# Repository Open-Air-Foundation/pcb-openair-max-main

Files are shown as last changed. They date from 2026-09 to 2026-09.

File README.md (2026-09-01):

# AirGradient Open Air Max — Hardware

> KiCad hardware design files for the [AirGradient Open Air Max](https://www.airgradient.com/professional/products/open-air-max/), a professional outdoor air quality monitor.

## Overview

Open Air Max is AirGradient's professional outdoor air quality monitor, designed for autonomous, off-grid operation. It measures PM2.5 (2× Plantower PMS5003), CO₂ (SenseAir Sunlight NDIR, 0–5,000 ppm), TVOCs/NOₓ (Sensirion SGP41), NO₂ (AlphaSense A43F) and O₃ (AlphaSense A431), plus temperature and humidity (Sensirion SHT40), in a UV-resistant, weatherproof ASA enclosure with wall or pole mounting (model O-M-1PPSTON-CE; CE, RoHS, REACH, and FCC certified).

Data is reported over Wi-Fi (2.4 GHz IEEE 802.11 b/g/n) or 4G cellular (LTE Cat 1). Power comes from a 10 W solar panel charging a user-replaceable pack of three 3,500 mAh Li-ion 18650 cells in series (3S), managed by a dedicated battery management system and a low-power design throughout.

This repository contains the monitor's main PCB: the ESP32-C6 MCU, solar/USB-C charging and power path, battery management, and the interfaces the sensor modules and the cellular CE card plug into — complete with schematics, PCB layout, bundled 3D models, and the production output set.

## Design structure

The design is a single 4-layer board (signal / power plane / ground plane / signal) drawn across three schematic sheets:

| Sheet | File | Contents |
|---|---|---|
| Root | `PCB/openair-max/One-Air-Max.kicad_sch` | MCU, power distribution, sensor and CE-card interfaces |
| Battery holder | `PCB/openair-max/Battery-Holder.kicad_sch` | 18650 battery interface and BMS |
| Solar module | `PCB/openair-max/Solar-Module.kicad_sch` | Charger and solar input conditioning |

## Repository structure

```
PCB/
└── openair-max/             # Main PCB (schematic, layout, DRC rules, production/)
libraries/                   # Shared 3D model libraries
├── 3d/                      # STEP models
└── easyeda2kicad/           # easyeda2kicad WRL models
```

## Key components

| Function | Part | Ref |
|---|---|---|
| MCU / Wi-Fi / BLE | ESP32-C6-WROOM-1-N8 | U1 |
| Buck converter | TPS62902 | U2 |
| Hardware watchdog timer | TPL5010 | U3 |
| Battery management system (BMS) | BQ7790512 (BQ76905 family) | U4 |
| Battery charger (solar + USB-C) | BQ25798 | U5 |
| Boost converter | TPS62903 | U6 |
| Power mux / load switch (RC soft-start) | TPS2117 | U7 |
| I²C-to-dual-UART bridge | WK2132 | U8 |
| EEPROM (2 Mbit, optional — DNP) | AT24CM02 | U12 |
| High-side load switches (switched sensor rails) | TPS27081A | U13–U19 |

**Power architecture:** The BQ25798 charger takes two power inputs — the solar cell on **VAC1** and USB-C on **VAC2** — and charges the 3S 18650 pack behind the BQ76905 BMS. The system rail is switched through the TPS2117 with an RC soft-start network to limit inrush current, and a 470 µF bulk capacitor ahead of the load switch provides brownout immunity.

## Plug-in modules

The gas sensors and the cellular option are separate boards that plug into this board's connectors. The assembled Open Air Max (O-M-1PPSTON-CE) carries all of them:

| Module | Repository | Connector on this board |
|---|---|---|
| SUNX CO₂ sensor module (SenseAir Sunlight, UART) | [pcb-module-sunx](https://github.com/Open-Air-Foundation/pcb-module-sunx) | `CO2` — 8-pin Molex PicoBlade: switched 5 V (VOUT2, EN_CO2 = IO5), GND, UART0 (IO0/IO1) |
| SGP41 TVOC/NOₓ sensor module (I²C) | [pcb-module-sgp41](https://github.com/Open-Air-Foundation/pcb-module-sgp41) | `I2C1` / `I2C2` — 1×4 sockets, 2.54 mm: 3.3 V, GND, SCL (IO6), SDA (IO7) |
| SHT4x temperature/humidity sensor module (I²C) | [pcb-module-sht40](https://github.com/Open-Air-Foundation/pcb-module-sht40) | `I2C1` / `I2C2` — the two sockets are identical; one takes the SGP41 module, the other the SHT4x module |
| AlphaSense ADC module — NO₂ (A43F) and O₃ (A431), I²C | [pcb-module-alphasense-adc](https://github.com/Open-Air-Foundation/pcb-module-alphasense-adc) | `NO2` — 8-pin Molex PicoBlade: switched 5 V and 3.3 V (VOUT6/VOUT5, EN_NO2 = IO4), GND, I²C |
| CE card — 4G cellular (LTE Cat 1) | [pcb-module-ce-card](https://github.com/Open-Air-Foundation/pcb-module-ce-card) | `CE1` — 8-pin Molex PicoBlade: switched 5 V and 3.3 V (VOUT4/VOUT3, EN_CE = IO15), power/reset control (IO23, IO21), UART (IO16/IO17) |

The particulate sensors (2× Plantower PMS5003) plug straight into the `PM1`/`PM2` PicoBlade sockets (switched 5 V + UART through the WK2132 bridge) and have no module board of their own. `I2C3` (4-pin, 1.25 mm; I²C) and `IO1` (8-pin PicoBlade: 5 V, 3.3 V, I²C, IO18–IO20) are spare expansion connectors.

## Toolchain

- **KiCad 10** (file format 2026-02). Symbols and footprints are embedded in the design files; all 3D models are bundled in `libraries/` and referenced project-relative — the project opens without any extra library setup.
- **[Fabrication Toolkit](https://github.com/bennymeg/Fabrication-Toolkit)** plugin — generates the Gerber/BOM/CPL production set in JLCPCB-compatible format.
- Active DRC rules are in `PCB/openair-max/One-Air-Max.kicad_dru`; `PCB/openair-max/DRC/JLCPCB.kicad_dru` is a slightly stricter JLCPCB reference template.

## Fabrication

`PCB/openair-max/production/` holds the ready-to-order set for the released version: Gerber zip, BOM, designators, and pick-and-place positions (generated with Fabrication Toolkit, LCSC part numbers for assembly at JLCPCB).

## Versioning & releases

Hardware revisions are tagged on this repository. Per-version release notes — chip-level changes and the matching production file set — are published on the [GitHub Releases](../../releases) page.

## Related repositories

- [firmware-openair-max](https://github.com/Open-Air-Foundation/firmware-openair-max) — ESP32-C6 firmware for this board
- [pcb-module-sunx](https://github.com/Open-Air-Foundation/pcb-module-sunx) — SUNX CO₂ sensor module (SenseAir Sunlight)
- [pcb-module-sgp41](https://github.com/Open-Air-Foundation/pcb-module-sgp41) — SGP41 TVOC/NOₓ sensor module
- [pcb-module-sht40](https://github.com/Open-Air-Foundation/pcb-module-sht40) — SHT4x temperature/humidity sensor module
- [pcb-module-alphasense-adc](https://github.com/Open-Air-Foundation/pcb-module-alphasense-adc) — AlphaSense ADC module (NO₂ / O₃ electrochemical sensors)
- [pcb-module-ce-card](https://github.com/Open-Air-Foundation/pcb-module-ce-card) — 4G cellular extension (CE) card; the assembled Open Air Max includes this card, fitted to the CE1 connector

## License

This is open-source hardware. The design files in this repository are licensed under the
[Creative Commons Attribution-ShareAlike 4.0 International (CC BY-SA 4.0)](https://creativecommons.org/licenses/by-sa/4.0/) license — see [LICENSE](LICENSE).

You are free to use, modify, and manufacture these designs, including commercially, provided you credit AirGradient and share derivative designs under the same license.

## Maintainers

AirGradient hardware team.

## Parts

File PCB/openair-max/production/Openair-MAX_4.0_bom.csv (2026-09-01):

Designator | Footprint | Quantity | Value | LCSC Part #
_6, _5, _4 | 212a6856-f275-4822-a761-75b07884269b | 3
_3, _2, | bce4f5f5-1da5-494e-a908-01ed689de916 | 3
BAT1 | BAT-SMD_BH-18650-B5BA016 | 1 | BH-18650-B5BA016 | C19184086
C1, C10, C11, C12, C13, C50, C51, C52, C53, C65, C7, C70, C85, C9 | C0402 | 14 | 0.1uF | C309458
C14, C57, C58, C68, C74, C82, C86 | C0402 | 7 | 22uF | C6119813
C15, C16, C17, C18, C19, C21, C24, C25 | C0603 | 8 | 0.1uF/50V | C14663
C2 | C0805 | 1 | 10uF/25V | C3039694
C20, C22 | C0402 | 2 | 1uF/50V | C7500380
C23, C27, C30 | C1206 | 3 | 10uF/25V | C9807
C26, C47 | C0402 | 2 | 0.1uF/25V | C100072
C28, C29 | C0402 | 2 | 47nF/50V | C272875
C3 | C1206 | 1 | 22uF/16V | C7472972
C31, C34, C37, C39, C89, C90 | C0402 | 6 | 0.1uF/50V | C77020
C32, C59, C60, C61, C62, C64, C84 | C0402 | 7 | 2.2uF | C385032
C33, C35, C38, C40 | C1206 | 4 | 10uF/50V | C13585
C36 | C0603 | 1 | 4.7uF/16V | C22399629
C4, C49 | C0402 | 2 | 3.3nF | C541378
C41, C87, C88 | C0402 | 3 | 1nF/50V | C77018
C42, C44, C5, C63 | C0402 | 4 | 0.1uF | C1525
C43, C45 | C1206 | 2 | 10uF | C109464
C46, C48 | C0805 | 2 | 22uF/25V | C602037
C54, C55 | C0402 | 2 | 22pF_NM | C1555
C56 | C0402 | 1 | 0.1nF | C106200
C6 | C0603 | 1 | 22uF | C109447
C66, C73, C76, C77, C78, C79, C80, C81, C83 | C0402 | 9 | 1uF | C14445
C67 | C0603 | 1 | 500pF | C1624
C69 | CASE-D_7343 | 1 | 6TPE470MAZU | C79114
C8 | C0402 | 1 | 10nF | C541371
C91, C94 | C0402 | 2 | 2.2uF/35V | C6119793
CE1 | CONN-SMD_HC-1.25-8PWT | 1 | HC-1.25-8PWT | C2845385
CO2, IO1, NO2, PM1, PM2 | CONN-SMD_8P-P1.25_HC-1.25-8PLT | 5 | HC-1.25-8PLT | C2845394
D1 | SOD2512X80N | 1 | BAS16J_135
D2 | SOD-323_L1.8-W1.3-LS2.5-RD | 1 | MMSZ5246BS-7-F | C151819
D3 | SMB_L4.4-W3.6-LS5.3-RD | 1 | SMBJ24A_C908801 | C908801
D4, D5, D6, D7 | SOD-123_L2.7-W1.6-LS3.7-FD | 4 | B5817W_C7420328 | C7420328
D8, D9 | SOD-523_L1.2-W0.8-LS1.6-RD | 2 | BZT52C12T-7 | C507911
DC1 | DC-IN-SMD_DC-045A-13A | 1 | DC-045A-13A | C707277
F1 | F1206 | 1 | 2A-16V | C2685749
FB1 | L0805 | 1 | PBY201209T-601Y-N | C108304
I2C1, I2C2 | HDR-TH_4P-P2.54-V-F | 2 | Conn_01x04 | C2718488
I2C3 | CONN-SMD_1.25-4PWB | 1 | 1.25-4PWB | C2905011
L1 | IND-SMD_L7.1-W6.5-P5.60 | 1 | SPM6530T-1R0M120 | C87572
L2 | IND-SMD_L4.0-W4.0_XAL4030-332MEC | 1 | XGL4020-102MEC | C5357696
L3 | IND-SMD_L4.0-W4.0_XGL4020 | 1 | YSMC0420V-1R0M | C7433091
LED2 | LED-TH_BD3.8-P2.54-FD_BLUE | 1 | XL-304UBC | C2895465
LED3 | LED0603-RD_RED | 1 | FC-DA1608HRK-620D | C84263
NTC1 | R0805 | 1 | KNTC0805/10KF3950 | C2892549
PWR_SW1 | SW-TH_TK-6580A8-1 | 1 | TK-6580A8-1 | C528772
Q1, Q2 | PQFN-8_L5.8-W4.9-P1.27-LS6.0-BL | 2 | CSD18534Q5A
Q3, Q4, Q5, Q6 | VSON-8_3.3x3.3mm_P0.65mm_NexFET | 4 | CSD17577Q3A | C201632
R1, R2 | R0402 | 2 | 5.1K | C105872
R10, R13, R36 | R0402 | 3 | 100 | C606168
R11 | R2512 | 1 | 10m / 1W | C705061
R12, R14, R15, R9 | R0402 | 4 | 1K | C851849
R16 | R0603 | 1 | 10.5K | C137808
R17, R19 | R0603 | 2 | 5.1K | C105580
R18 | R0603 | 1 | 10M | C114606
R20 | R0603 | 1 | 1M | C105578
R21 | R0603 | 1 | 3M | C126361
R22 | R0603 | 1 | 10K | C98220
R24 | R0603 | 1 | 470K | C114622
R26, R27, R33, R41, R51, R72 | R0603 | 6 | 0 | C100044
R28, R29, R30, R32, R4, R45, R49, R5, R50 | R0402 | 9 | 10K | C60490
R3, R31, R37, R6 | R0402 | 4 | 100K | C60491
R34 | R0603 | 1 | 5.23K | C185317
R35 | R0603 | 1 | 255K | C295887
R38 | R0603 | 1 | 30.1K | C137745
R39 | R0402 | 1 | 200K | C606170
R40 | R0603 | 1 | 27K | C114614
R42, R57 | R0603 | 2 | 7.15K | C861562
R43 | R0402 | 1 | 16.9K | C163488
R44 | R0603 | 1 | 5K | C862232
R46 | R0402 | 1 | 1M | C327799
R47, R58, R59, R60, R61, R64, R65, R66, R67, R69, R70, R74, R81 | R0402 | 13 | 10K | C327797
R48 | R0402 | 1 | 5.1K | C413002
R52 | R0402 | 1 | 113k | C273332
R53, R54, R55, R68, R79, R80, R82 | R0402 | 7 | 1K | C106235
R56 | R0402 | 1 | 24.9k | C226371
R62, R63 | R0402 | 2 | 22 | C114765
R7 | R0402 | 1 | 51K | C107229
R71 | R0402 | 1 | 210 | C2076880
R83, R86 | R0402 | 2 | 2 | C514778
R84, R85 | R0402 | 2 | 294 | C477682
SW1 | KEY-TH_TS-1096-A1B2-D2 | 1 | TS-1096-A1B2-D2 | C492993
U1 | WIRELM-SMD_ESP32-C6-WROOM-1 | 1 | ESP32-C6-WROOM-1-N8 | C5366877
U12 | SOIC-8_L4.9-W3.9-P1.27-LS6.0-BL | 1 | AT24CM02-SSHD-B | C220680
U13, U14, U15, U16, U17, U18, U19 | SOT-23-6_L2.9-W1.6-P0.95-LS2.8-BR | 7 | TPS27081ADDCR | C128404
U2 | VQFN-HR-9_L2.0-W1.5-P0.50-TL | 1 | TPS62902RPJR | C2870154
U3 | SOT-23-6_L2.9-W1.6-P0.95-LS2.8-BR | 1 | TPL5010DDCR | C473912
U4 | TSSOP-20_L6.5-W4.4-P0.65-LS6.4-BL | 1 | BQ7790512PWR | C555146
U5 | QFN-29_L4.0-W4.0-P0.40-TL-BQ25792RQMR | 1 | BQ25798RQMR | C2876593
U6 | VQFNHR-9_L2.2-W2.0_TPS62993QRYTRQ1 | 1 | TPS62903QRYTRQ1_C20345985 | C20345985
U7 | SOT-583-8_L2.1-W1.2-P0.50-LS1.6-BL | 1 | TPS2117DRLR_C22399676 | C22399676
U8 | SSOP-16_L7.2-W5.3-P0.65-LS7.8-BL | 1 | WK2132-ISSG | C401039
USB1 | USB-C-SMD_G-SWITCH_GT-USB-7010ASV | 1 | GT-USB-7010ASV | C2988369
X1 | OSC-SMD_L5.0-W3.2 | 1 | SMD-5032_2P 14.7456MHZ 20PF 20PPM | C362355

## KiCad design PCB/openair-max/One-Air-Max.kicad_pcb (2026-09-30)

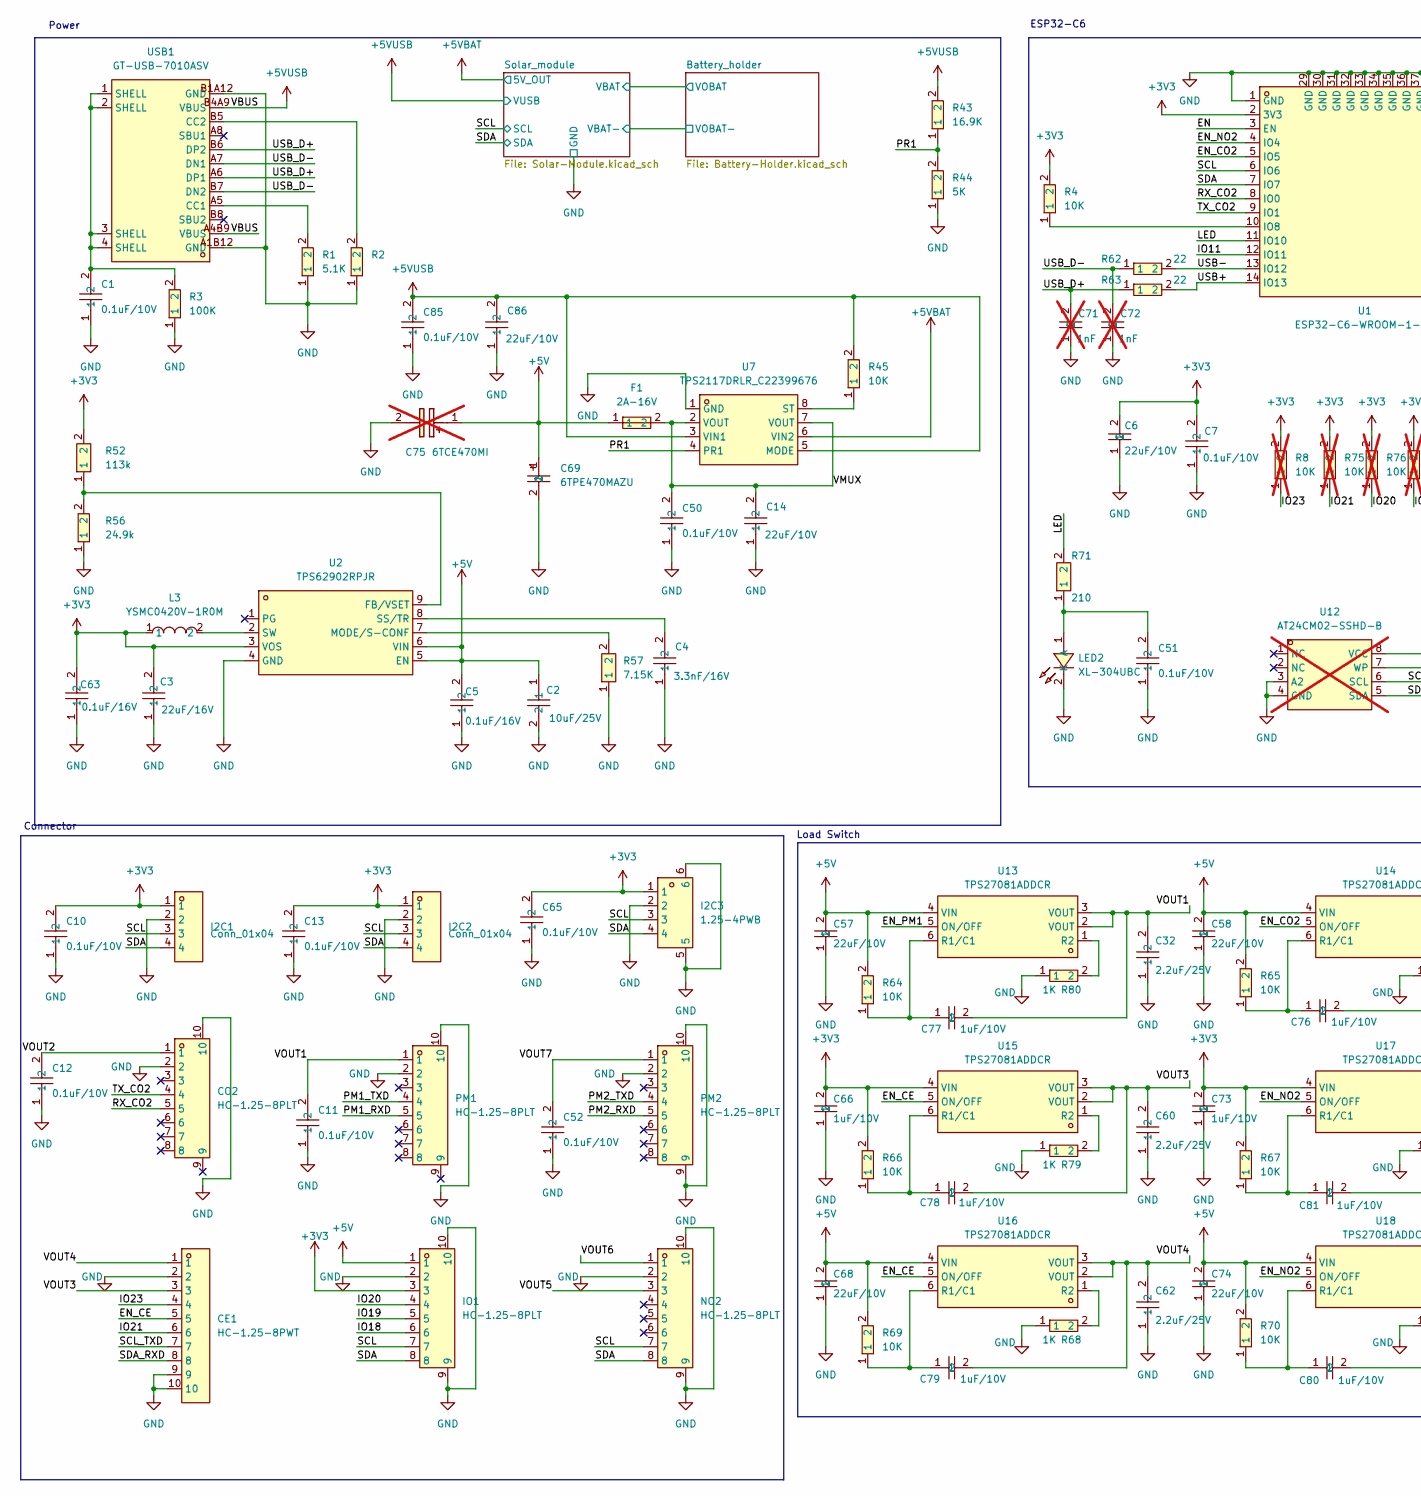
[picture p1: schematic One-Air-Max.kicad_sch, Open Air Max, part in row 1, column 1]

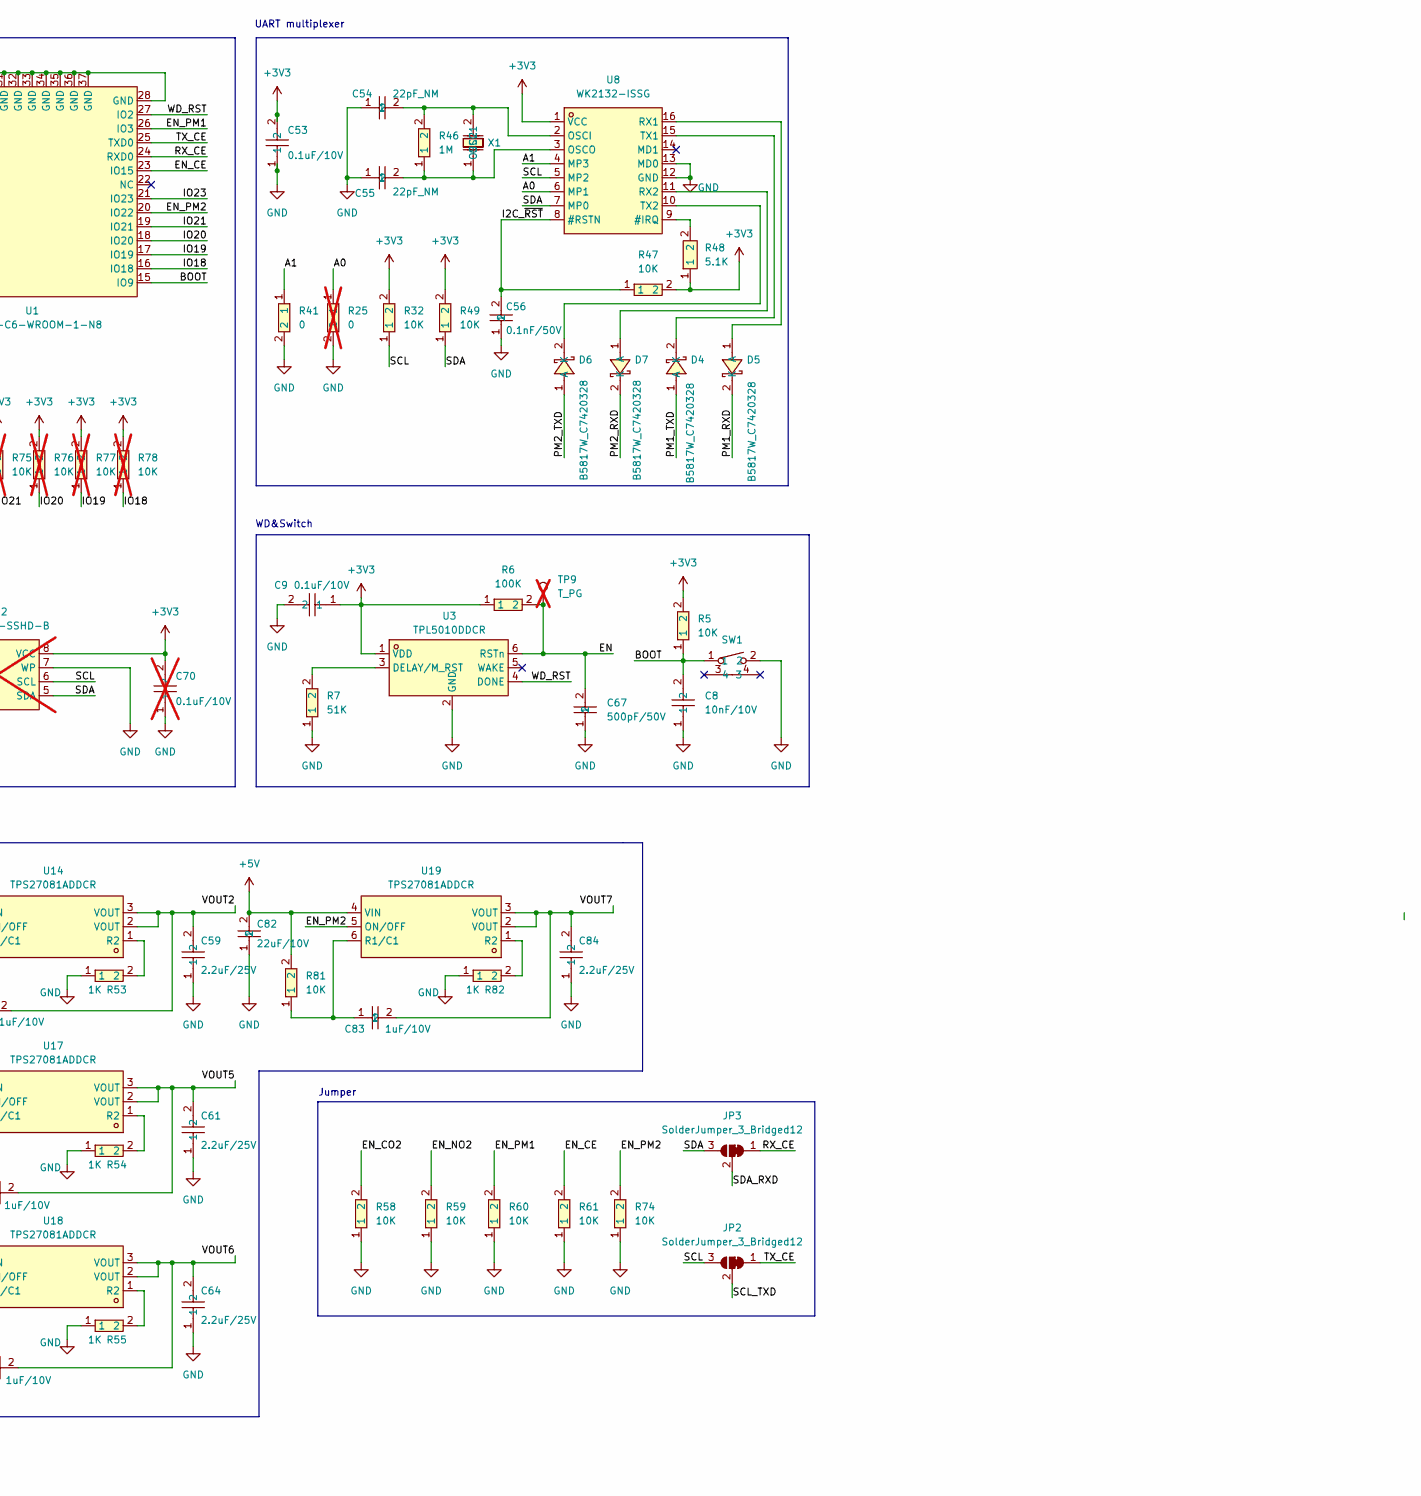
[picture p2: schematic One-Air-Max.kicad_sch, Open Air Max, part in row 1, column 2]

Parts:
C1, C7, C9, C10, C11, C12, C13, C50, C51, C52, C53, C65, C85: 0.1uF/10V; C0402; LCSC Part C309458
C2: 10uF/25V; C0805; LCSC Part C3039694
C3: 22uF/16V; C1206; LCSC Part C7472972
C4: 3.3nF/16V; C0402; LCSC Part C541378
C5, C63: 0.1uF/16V; C0402; LCSC Part C1525
C6: 22uF/10V; C0603; LCSC Part C109447
C8: 10nF/10V; C0402; LCSC Part C541371
C14, C57, C58, C68, C74, C82, C86: 22uF/10V; C0402; LCSC Part C6119813
C32, C59, C60, C61, C62, C64, C84: 2.2uF/25V; C0402; LCSC Part C385032
C54, C55: 22pF_NM; C0402; LCSC Part C1555
C56: 0.1nF/50V; C0402; LCSC Part C106200
C66, C73, C76, C77, C78, C79, C80, C81, C83: 1uF/10V; C0402; LCSC Part C14445
C67: 500pF/50V; C0603; LCSC Part C1624
C69: 6TPE470MAZU; CASE-D_7343; LCSC Part C79114
C70: 0.1uF/10V; C0402; LCSC Part C309458; not fitted
C71, C72: 1nF; C0402; LCSC Part C106205; not fitted
C75: 6TCE470MI; CASE-D_7343; Manufacturer Part 6TCE470MI; not fitted
CE1: HC-1.25-8PWT; CONN-SMD_HC-1.25-8PWT; LCSC Part C2845385
CO2: HC-1.25-8PLT; CONN-SMD_8P-P1.25_HC-1.25-8PLT; LCSC Part C2845394
D4, D5, D6, D7: B5817W_C7420328; SOD-123_L2.7-W1.6-LS3.7-FD; LCSC Part C7420328
F1: 2A-16V; F1206; LCSC Part C2685749
I2C1, I2C2: Conn_01x04; HDR-TH_4P-P2.54-V-F; LCSC Part C2718488
I2C3: 1.25-4PWB; CONN-SMD_1.25-4PWB; LCSC Part C2905011
IO1: HC-1.25-8PLT; CONN-SMD_8P-P1.25_HC-1.25-8PLT; LCSC Part C2845394
JP2, JP3: SolderJumper_3_Bridged12; SolderJumper-3_P1.3mm_Bridged12_RoundedPad1.0x1.5mm
L3: YSMC0420V-1R0M; IND-SMD_L4.0-W4.0_XGL4020; LCSC Part C7433091
LED2: XL-304UBC; LED-TH_BD3.8-P2.54-FD_BLUE; LCSC Part C2895465
NO2: HC-1.25-8PLT; CONN-SMD_8P-P1.25_HC-1.25-8PLT; LCSC Part C2845394
PM1, PM2: HC-1.25-8PLT; CONN-SMD_8P-P1.25_HC-1.25-8PLT; LCSC Part C2845394
R1, R2: 5.1K; R0402; LCSC Part C105872
R3, R6: 100K; R0402; LCSC Part C60491
R4, R5, R32, R45, R49: 10K; R0402; LCSC Part C60490
R7: 51K; R0402; LCSC Part C107229
R8, R75, R76, R77, R78: 10K; R0402; LCSC Part C60490; not fitted
R25: 0; R0603; LCSC Part C100044; not fitted
R41: 0; R0603; LCSC Part C100044
R43: 16.9K; R0402; LCSC Part C163488
R44: 5K; R0603; LCSC Part C862232
R46: 1M; R0402; LCSC Part C327799
R47, R58, R59, R60, R61, R64, R65, R66, R67, R69, R70, R74, R81: 10K; R0402; LCSC Part C327797
R48: 5.1K; R0402; LCSC Part C413002
R52: 113k; R0402; LCSC Part C273332
R53, R54, R55, R68, R79, R80, R82: 1K; R0402; LCSC Part C106235
R56: 24.9k; R0402; LCSC Part C226371
R57: 7.15K; R0603; LCSC Part C861562
R62, R63: 22; R0402; LCSC Part C114765
R71: 210; R0402; LCSC Part C2076880
SW1: TS-1096-A1B2-D2; KEY-TH_TS-1096-A1B2-D2; LCSC Part C492993
TP9: T_PG; TestPoint_Pad_D1.5mm; not fitted
U1: ESP32-C6-WROOM-1-N8; WIRELM-SMD_ESP32-C6-WROOM-1; LCSC Part C5366877
U2: TPS62902RPJR; VQFN-HR-9_L2.0-W1.5-P0.50-TL; LCSC Part C2870154
U3: TPL5010DDCR; SOT-23-6_L2.9-W1.6-P0.95-LS2.8-BR; LCSC Part C473912
U7: TPS2117DRLR_C22399676; SOT-583-8_L2.1-W1.2-P0.50-LS1.6-BL; LCSC Part C22399676
U8: WK2132-ISSG; SSOP-16_L7.2-W5.3-P0.65-LS7.8-BL; LCSC Part C401039
U12: AT24CM02-SSHD-B; SOIC-8_L4.9-W3.9-P1.27-LS6.0-BL; LCSC Part C220680; not fitted
U13, U14, U15, U16, U17, U18, U19: TPS27081ADDCR; SOT-23-6_L2.9-W1.6-P0.95-LS2.8-BR; LCSC Part C128404
USB1: GT-USB-7010ASV; USB-C-SMD_G-SWITCH_GT-USB-7010ASV; LCSC Part C2988369
X1: SMD-5032_2P 14.7456MHZ 20PF 20PPM; OSC-SMD_L5.0-W3.2; LCSC Part C362355

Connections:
+3V3: C3.2, C6.2, C7.2, C9.1, C10.2, C13.2, C53.2, C63.2, C65.2, C66.2, C70.2, C73.2, I2C1.1, I2C2.1, I2C3.1, IO1.3, L3.1, R4.2, R5.2, R6.1, R8.2, R32.2, R47.2, R48.1, R49.2, R52.2, R66.2, R67.2, R75.2, R76.2, R77.2, R78.2, U1.2 (3V3), U2.3 (VOS), U3.1 (VDD), U8.1 (VCC), U12.8 (VCC), U15.4 (VIN), U17.4 (VIN); also elsewhere on the board
+5V: C2.1, C5.2, C57.2, C58.2, C68.2, C69.1, C74.2, C75.1 (+), C82.2, F1.1, IO1.1, R64.2, R65.2, R69.2, R70.2, R81.2, U2.5 (EN), U2.6 (VIN), U13.4 (VIN), U14.4 (VIN), U16.4 (VIN), U18.4 (VIN), U19.4 (VIN)
+5VBAT: U7.6 (VIN2); also elsewhere on the board
+5VUSB: C85.2, C86.2, R43.2, R45.2, U7.3 (VIN1), U7.5 (MODE), USB1.A4B9 (VBUS), USB1.B4A9 (VBUS); also elsewhere on the board
/A0: R25.1, U8.6 (MP1)
/A1: R41.1, U8.4 (MP3)
/BOOT: C8.2, R5.1, SW1.1, U1.15 (IO9)
/EN: C67.2, R6.2, TP9.1 (1_1), U1.3 (EN), U3.6 (RSTn)
/EN_CE: CE1.5, R61.2, U1.23 (IO15), U15.5 (ON/OFF), U16.5 (ON/OFF)
/EN_CO2: R58.2, U1.5 (IO5), U14.5 (ON/OFF)
/EN_NO2: R59.2, U1.4 (IO4), U17.5 (ON/OFF), U18.5 (ON/OFF)
/EN_PM1: R60.2, U1.26 (IO3), U13.5 (ON/OFF)
/EN_PM2: R74.2, U1.20 (IO22), U19.5 (ON/OFF)
/I2C_~RST: C56.2, R47.1, U8.8 (#RSTN)
/IO11: U1.12 (IO11)
/IO18: IO1.6, R78.1, U1.16 (IO18)
/IO19: IO1.5, R77.1, U1.17 (IO19)
/IO20: IO1.4, R76.1, U1.18 (IO20)
/IO21: CE1.6, R75.1, U1.19 (IO21)
/IO23: CE1.4, R8.1, U1.21 (IO23)
/LED: R71.2, U1.11 (IO10)
/PM1_RXD: D5.2 (K), PM1.5
/PM1_TXD: D4.1 (A), PM1.4
/PM2_RXD: D7.2 (K), PM2.5
/PM2_TXD: D6.1 (A), PM2.4
/PR1: R43.1, R44.2, U7.4 (PR1)
/RX_CE: JP3.1 (A), U1.24 (RXD0)
/RX_CO2: CO2.5, U1.8 (IO0)
/SCL: I2C1.3, I2C2.3, I2C3.3, IO1.7, JP2.3 (B), NO2.7, R32.1, U1.6 (IO6), U8.5 (MP2), U12.6 (SCL); also elsewhere on the board
/SCL_TXD: CE1.7, JP2.2 (C)
/SDA: I2C1.4, I2C2.4, I2C3.4, IO1.8, JP3.3 (B), NO2.8, R49.1, U1.7 (IO7), U8.7 (MP0), U12.5 (SDA); also elsewhere on the board
/SDA_RXD: CE1.8, JP3.2 (C)
/TX_CE: JP2.1 (A), U1.25 (TXD0)
/TX_CO2: CO2.4, U1.9 (IO1)
/USB+: R63.2, U1.14 (IO13)
/USB-: R62.2, U1.13 (IO12)
/USB_D+: C71.2, R63.1, USB1.A6 (DP1), USB1.B6 (DP2)
/USB_D-: C72.2, R62.1, USB1.A7 (DN1), USB1.B7 (DN2)
/VMUX: C14.2, C50.2, F1.2, U7.2 (VOUT), U7.7 (VOUT)
/VOUT1: C11.2, C32.2, C77.2, PM1.1, U13.2 (VOUT), U13.3 (VOUT)
/VOUT2: C12.2, C59.2, C76.2, CO2.1, U14.2 (VOUT), U14.3 (VOUT)
/VOUT3: C60.2, C78.2, CE1.3, U15.2 (VOUT), U15.3 (VOUT)
/VOUT4: C62.2, C79.2, CE1.1, U16.2 (VOUT), U16.3 (VOUT)
/VOUT5: C61.2, C81.2, NO2.3, U17.2 (VOUT), U17.3 (VOUT)
/VOUT6: C64.2, C80.2, NO2.1, U18.2 (VOUT), U18.3 (VOUT)
/VOUT7: C52.2, C83.2, C84.2, PM2.1, U19.2 (VOUT), U19.3 (VOUT)
/WD_RST: U1.27 (IO2), U3.4 (DONE)
GND: C1.1, C2.2, C3.1, C4.1, C5.1, C6.1, C7.1, C8.1, C9.2, C10.1, C11.1, C12.1, C13.1, C14.1, C32.1, C50.1, C51.1, C52.1, C53.1, C54.1, C55.1, C56.1, C57.1, C58.1, C59.1, C60.1, C61.1, C62.1, C63.1, C64.1, C65.1, C66.1, C67.1, C68.1, C69.2, C70.1, C71.1, C72.1, C73.1, C74.1, C75.2 (-), C82.1, C84.1, C85.1, C86.1, CE1.2, CE1.9, CE1.10, CO2.2, CO2.10, I2C1.2, I2C2.2, I2C3.2, I2C3.5, I2C3.6, IO1.2, IO1.9, IO1.10, LED2.2 (K), NO2.2, NO2.9, NO2.10, PM1.2, PM1.10, PM2.2, PM2.9, PM2.10, R1.1, R2.1, R3.1, R7.1, R25.2, R41.2, R44.1, R53.1, R54.1, R55.1, R56.1, R57.1, R58.1, R59.1, R60.1, R61.1, R68.1, R74.1, R79.1, R80.1, R82.1, SW1.2, U1.1 (GND), U1.28 (GND), U1.29 (GND), U1.30 (GND), U1.31 (GND), U1.32 (GND), U1.33 (GND), U1.34 (GND), U1.35 (GND), U1.36 (GND), U1.37 (GND), U2.4 (GND), U3.2 (GND), U7.1 (GND), U8.12 (GND), U8.13 (MD0), U12.3 (A2), U12.4 (GND), U12.7 (WP), USB1.A1B12 (GND), USB1.B1A12 (GND); also elsewhere on the board
unnamed: C1.2, R3.2, USB1.1 (SHELL), USB1.2 (SHELL), USB1.3 (SHELL), USB1.4 (SHELL)
unnamed: D4.2 (K), U8.15 (TX1)
unnamed: D5.1 (A), U8.16 (RX1)
unnamed: D6.2 (K), U8.10 (TX2)
unnamed: D7.1 (A), U8.11 (RX2)
unnamed: C51.2, LED2.1 (A), R71.1
unnamed: R4.1, U1.10 (IO8)
unnamed: R52.1, R56.2, U2.9 (FB/VSET)
unnamed: R57.2, U2.7 (MODE/S-CONF)
unnamed: C4.2, U2.8 (SS/TR)
unnamed: L3.2, U2.2 (SW)
unnamed: R7.2, U3.3 (DELAY/M_RST)
unnamed: R45.1, U7.8 (ST)
unnamed: R48.2, U8.9 (#IRQ)
unnamed: C54.2, R46.2, U8.2 (OSCI), X1.2 (OSC2)
unnamed: C55.2, R46.1, U8.3 (OSCO), X1.1 (OSC1)
unnamed: C77.1, R64.1, U13.6 (R1/C1)
unnamed: R80.2, U13.1 (R2)
unnamed: C76.1, R65.1, U14.6 (R1/C1)
unnamed: R53.2, U14.1 (R2)
unnamed: C78.1, R66.1, U15.6 (R1/C1)
unnamed: R79.2, U15.1 (R2)
unnamed: C79.1, R69.1, U16.6 (R1/C1)
unnamed: R68.2, U16.1 (R2)
unnamed: C81.1, R67.1, U17.6 (R1/C1)
unnamed: R54.2, U17.1 (R2)
unnamed: C80.1, R70.1, U18.6 (R1/C1)
unnamed: R55.2, U18.1 (R2)
unnamed: C83.1, R81.1, U19.6 (R1/C1)
unnamed: R82.2, U19.1 (R2)
unnamed: R1.2, USB1.A5 (CC1)
unnamed: R2.2, USB1.B5 (CC2)

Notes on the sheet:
WD&Switch
Load Switch
Power
UART multiplexer
Connector
Jumper
ESP32-C6

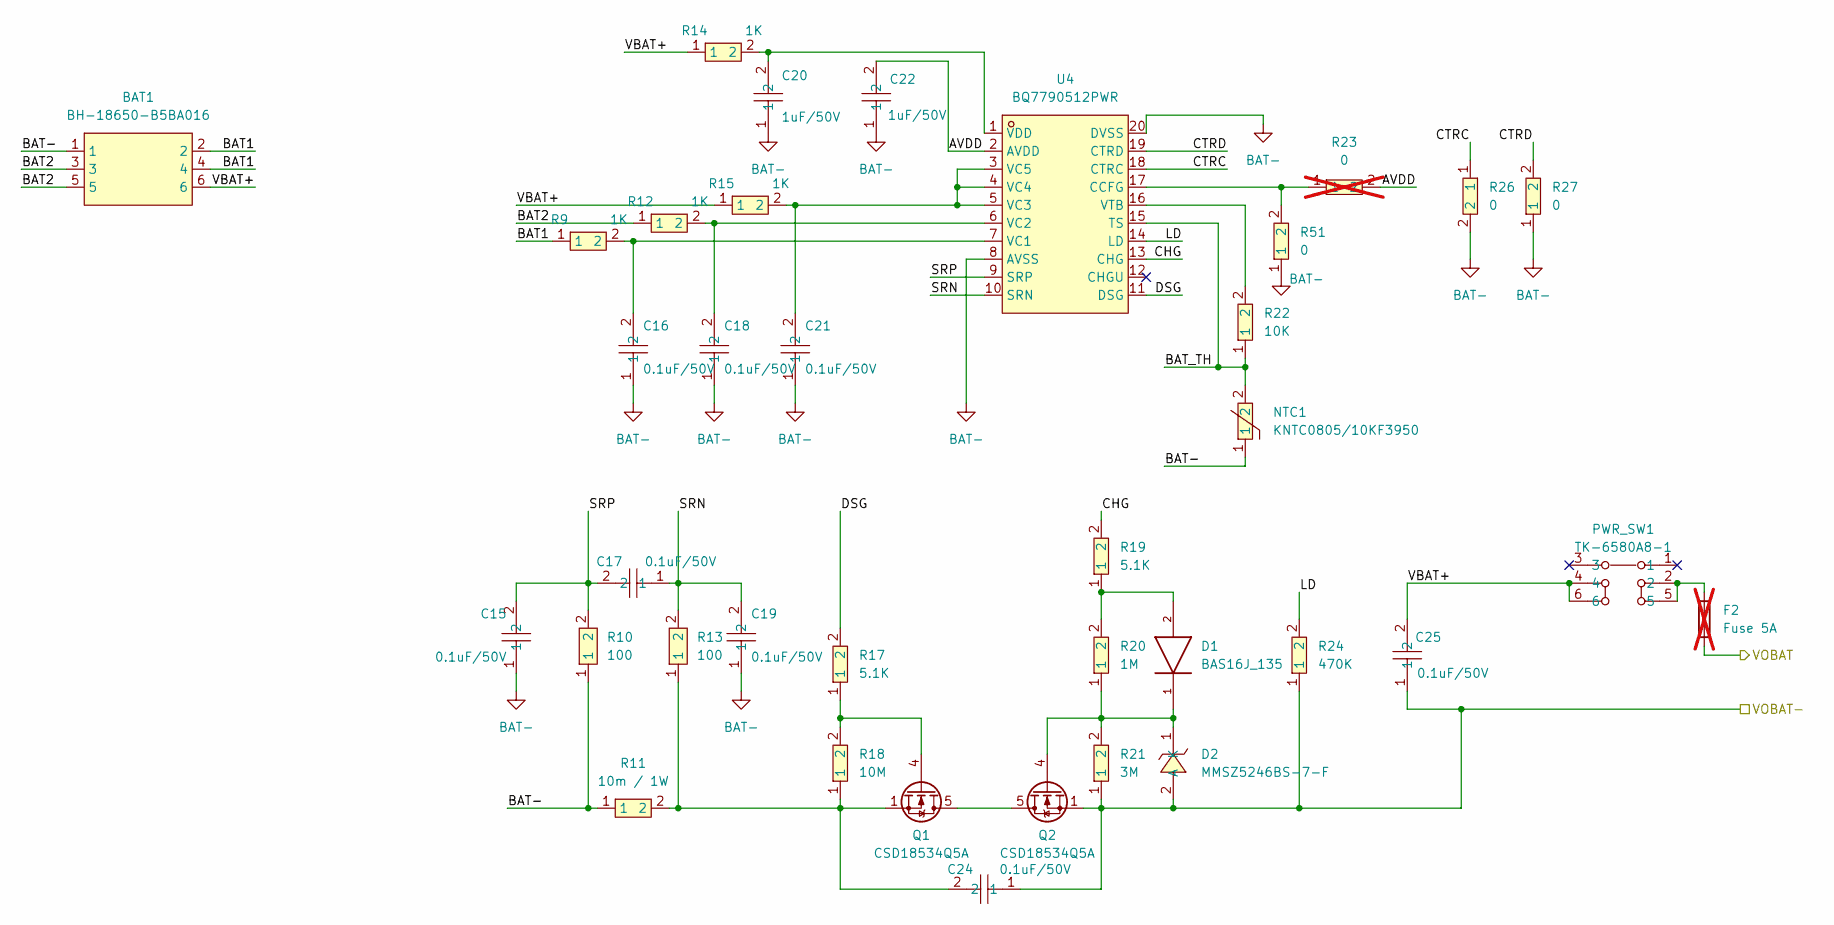
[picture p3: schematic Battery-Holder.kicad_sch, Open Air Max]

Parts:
BAT1: BH-18650-B5BA016; BAT-SMD_BH-18650-B5BA016; LCSC Part C19184086
C15, C16, C17, C18, C19, C21, C24, C25: 0.1uF/50V; C0603; LCSC Part C14663
C20, C22: 1uF/50V; C0402; LCSC Part C7500380
D1: BAS16J_135; SOD2512X80N; MOUSER_PART_NUMBER 771-BAS16J135
D2: MMSZ5246BS-7-F; SOD-323_L1.8-W1.3-LS2.5-RD; LCSC Part C151819
F2: Fuse 5A; PCB_fuse; not fitted
NTC1: KNTC0805/10KF3950; R0805; LCSC Part C2892549
PWR_SW1: TK-6580A8-1; SW-TH_TK-6580A8-1; LCSC Part C528772
Q1, Q2: CSD18534Q5A; PQFN-8_L5.8-W4.9-P1.27-LS6.0-BL
R9, R12, R14, R15: 1K; R0402; LCSC Part C851849
R10, R13: 100; R0402; LCSC Part C606168
R11: 10m / 1W; R2512; LCSC Part C705061
R17, R19: 5.1K; R0603; LCSC Part C105580
R18: 10M; R0603; LCSC Part C114606
R20: 1M; R0603; LCSC Part C105578
R21: 3M; R0603; LCSC Part C126361
R22: 10K; R0603; LCSC Part C98220
R23: 0; R0603; LCSC Part C100044; not fitted
R24: 470K; R0603; LCSC Part C114622
R26, R27, R51: 0; R0603; LCSC Part C100044
U4: BQ7790512PWR; TSSOP-20_L6.5-W4.4-P0.65-LS6.4-BL; LCSC Part C555146

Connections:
/Battery_holder/AVDD: C22.2, R23.2, U4.2 (AVDD)
/Battery_holder/BAT1: BAT1.2, BAT1.4, R9.1
/Battery_holder/BAT2: BAT1.3, BAT1.5, R12.1
/Battery_holder/BAT_TH: NTC1.2, R22.1, U4.15 (TS)
/Battery_holder/CHG: R19.2, U4.13 (CHG)
/Battery_holder/CTRC: R26.1, U4.18 (CTRC)
/Battery_holder/CTRD: R27.2, U4.19 (CTRD)
/Battery_holder/DSG: R17.2, U4.11 (DSG)
/Battery_holder/LD: R24.2, U4.14 (LD)
/Battery_holder/SRN: C17.1, C19.2, R13.2, U4.10 (SRN)
/Battery_holder/SRP: C15.2, C17.2, R10.2, U4.9 (SRP)
/Battery_holder/VBAT+: BAT1.6, C25.2, PWR_SW1.4, PWR_SW1.6, R14.1, R15.1
/Solar_module/VBAT: F2.1; also elsewhere on the board
BAT-: BAT1.1, C15.1, C16.1, C18.1, C19.1, C20.1, C21.1, C22.1, NTC1.1, R10.1, R11.1, R26.2, R27.1, R51.1, U4.8 (AVSS), U4.20 (DVSS)
unnamed: C24.2, Q1.1 (S), Q1.2 (S), Q1.3 (S), R11.2, R13.1, R18.1
unnamed: D1.2, R19.1, R20.2
unnamed: D1.1, D2.1 (K), Q2.4 (G), R20.1, R21.2
unnamed: F2.2, PWR_SW1.2, PWR_SW1.5
unnamed: Q1.5 (D), Q1.6 (S), Q1.7 (S), Q1.8 (S), Q2.5 (D), Q2.6 (S), Q2.7 (S), Q2.8 (S)
unnamed: Q1.4 (G), R17.1, R18.2
unnamed: R23.1, R51.2, U4.17 (CCFG)
unnamed: C16.2, R9.2, U4.7 (VC1)
unnamed: C18.2, R12.2, U4.6 (VC2)
unnamed: C21.2, R15.2, U4.3 (VC5), U4.4 (VC4), U4.5 (VC3)
unnamed: C20.2, R14.2, U4.1 (VDD)
unnamed: R22.2, U4.16 (VTB)
PGND: C24.1, C25.1, D2.2 (A), Q2.1 (S), Q2.2 (S), Q2.3 (S), R21.1, R24.1; also elsewhere on the board

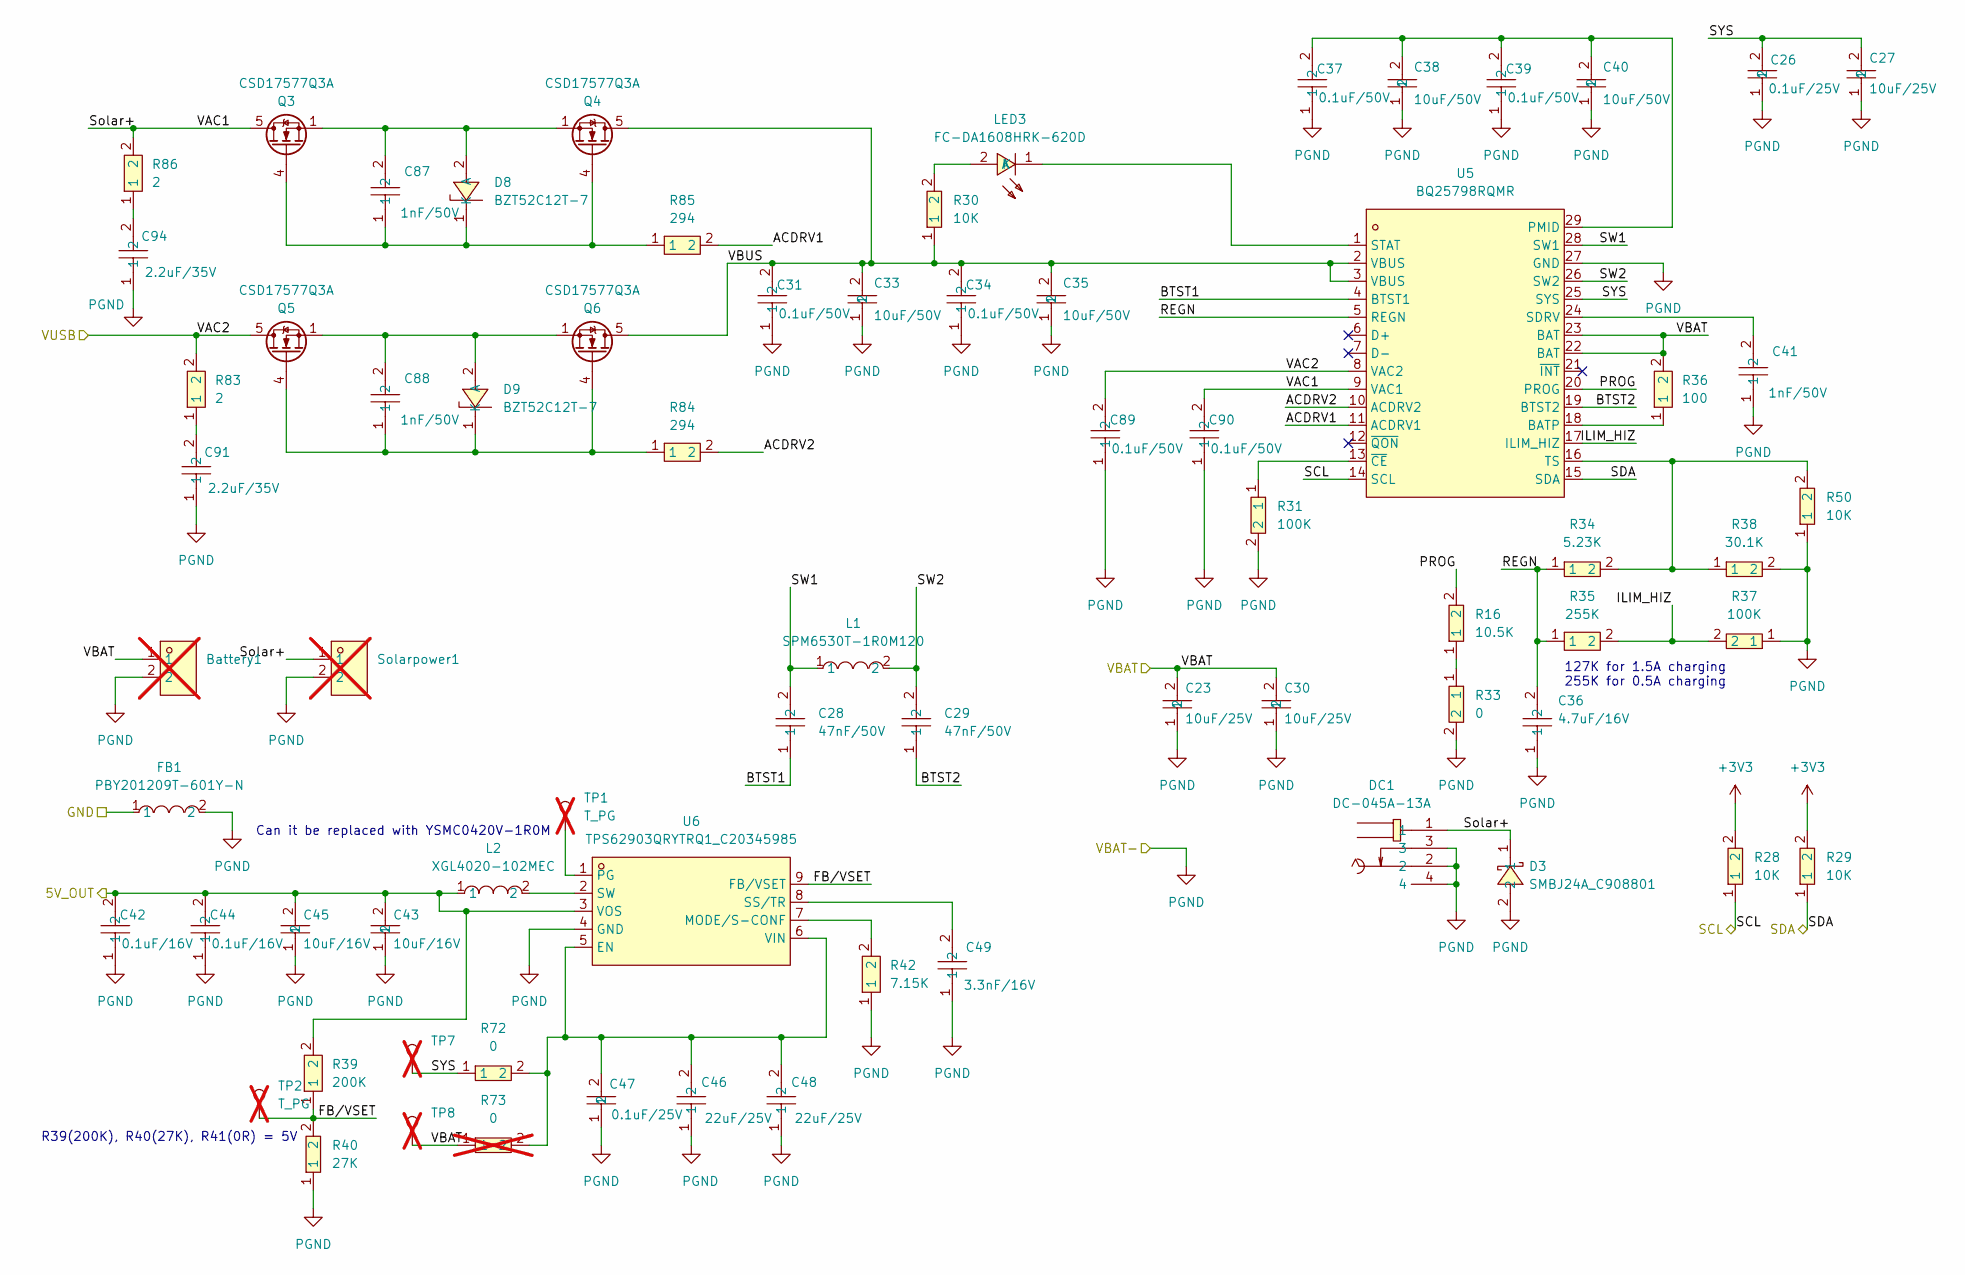
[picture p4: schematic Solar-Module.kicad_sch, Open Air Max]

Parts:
Battery1: ZX-PM2.54-1-2PY; HDR-TH_2P-P2.54-V-F; LCSC Part C7499322; not fitted
C23, C27, C30: 10uF/25V; C1206; LCSC Part C9807
C26, C47: 0.1uF/25V; C0402; LCSC Part C100072
C28, C29: 47nF/50V; C0402; LCSC Part C272875
C31, C34, C37, C39, C89, C90: 0.1uF/50V; C0402; LCSC Part C77020
C33, C35, C38, C40: 10uF/50V; C1206; LCSC Part C13585
C36: 4.7uF/16V; C0603; LCSC Part C22399629
C41, C87, C88: 1nF/50V; C0402; LCSC Part C77018
C42, C44: 0.1uF/16V; C0402; LCSC Part C1525
C43, C45: 10uF/16V; C1206; LCSC Part C109464
C46, C48: 22uF/25V; C0805; LCSC Part C602037
C49: 3.3nF/16V; C0402; LCSC Part C541378
C91, C94: 2.2uF/35V; C0402; LCSC Part C6119793
D3: SMBJ24A_C908801; SMB_L4.4-W3.6-LS5.3-RD; LCSC Part C908801
D8, D9: BZT52C12T-7; SOD-523_L1.2-W0.8-LS1.6-RD; LCSC Part C507911
DC1: DC-045A-13A; DC-IN-SMD_DC-045A-13A; LCSC Part C707277
FB1: PBY201209T-601Y-N; L0805; LCSC Part C108304
L1: SPM6530T-1R0M120; IND-SMD_L7.1-W6.5-P5.60; LCSC Part C87572
L2: XGL4020-102MEC; IND-SMD_L4.0-W4.0_XAL4030-332MEC; LCSC Part C5357696
LED3: FC-DA1608HRK-620D; LED0603-RD_RED; LCSC Part C84263
Q3, Q4, Q5, Q6: CSD17577Q3A; VSON-8_3.3x3.3mm_P0.65mm_NexFET; LCSC Part C201632
R16: 10.5K; R0603; LCSC Part C137808
R28, R29, R30, R50: 10K; R0402; LCSC Part C60490
R31, R37: 100K; R0402; LCSC Part C60491
R33, R72: 0; R0603; LCSC Part C100044
R34: 5.23K; R0603; LCSC Part C185317
R35: 255K; R0603; LCSC Part C295887
R36: 100; R0402; LCSC Part C606168
R38: 30.1K; R0603; LCSC Part C137745
R39: 200K; R0402; LCSC Part C606170
R40: 27K; R0603; LCSC Part C114614
R42: 7.15K; R0603; LCSC Part C861562
R73: 0; R0603; LCSC Part C100044; not fitted
R83, R86: 2; R0402; LCSC Part C514778
R84, R85: 294; R0402; LCSC Part C477682
Solarpower1: ZX-PM2.54-1-2PY; HDR-TH_2P-P2.54-V-F; LCSC Part C7499322; not fitted
TP1, TP2, TP7, TP8: T_PG; TestPoint_Pad_D1.5mm; not fitted
U5: BQ25798RQMR; QFN-29_L4.0-W4.0-P0.40-TL-BQ25792RQMR; LCSC Part C2876593
U6: TPS62903QRYTRQ1_C20345985; VQFNHR-9_L2.2-W2.0_TPS62993QRYTRQ1; LCSC Part C20345985

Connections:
+3V3: R28.2, R29.2; also elsewhere on the board
+5VBAT: C42.2, C43.2, C44.2, C45.2, L2.1, R39.2, U6.3 (VOS); also elsewhere on the board
+5VUSB: C89.2, Q5.5 (D), R83.2, U5.8 (VAC2); also elsewhere on the board
/SCL: R28.1, U5.14 (SCL); also elsewhere on the board
/SDA: R29.1, U5.15 (SDA); also elsewhere on the board
/Solar_module/ACDRV1: R85.2, U5.11 (ACDRV1)
/Solar_module/ACDRV2: R84.2, U5.10 (ACDRV2)
/Solar_module/BTST1: C28.1, U5.4 (BTST1)
/Solar_module/BTST2: C29.1, U5.19 (BTST2)
/Solar_module/FB/VSET: R39.1, R40.2, TP2.1 (1_1), U6.9 (FB/VSET)
/Solar_module/ILIM_HIZ: R35.2, R37.2, U5.17 (ILIM_HIZ)
/Solar_module/PROG: R16.2, U5.20 (PROG)
/Solar_module/REGN: C36.2, R34.1, R35.1, U5.5 (REGN)
/Solar_module/SW1: C28.2, L1.1, U5.28 (SW1)
/Solar_module/SW2: C29.2, L1.2, U5.26 (SW2)
/Solar_module/SYS: C26.2, C27.2, R72.1, TP7.1 (1_1), U5.25 (SYS)
/Solar_module/Solar+: C90.2, D3.1, DC1.1, Q3.5 (D), R86.2, Solarpower1.1, U5.9 (VAC1)
/Solar_module/VBAT: Battery1.1, C23.2, C30.2, R36.2, R73.1, TP8.1 (1_1), U5.22 (BAT), U5.23 (BAT); also elsewhere on the board
/Solar_module/VBUS: C31.2, C33.2, C34.2, C35.2, Q4.5 (D), Q6.5 (D), R30.1, U5.2 (VBUS), U5.3 (VBUS)
GND: FB1.1; also elsewhere on the board
unnamed: C91.2, R83.1
unnamed: C94.2, R86.1
unnamed: C87.2, D8.2 (A), Q3.1 (S), Q3.2 (S), Q3.3 (S), Q4.1 (S), Q4.2 (S), Q4.3 (S)
unnamed: C87.1, D8.1 (K), Q3.4 (G), Q4.4 (G), R85.1
unnamed: C88.2, D9.2 (A), Q5.1 (S), Q5.2 (S), Q5.3 (S), Q6.1 (S), Q6.2 (S), Q6.3 (S)
unnamed: C88.1, D9.1 (K), Q5.4 (G), Q6.4 (G), R84.1
unnamed: LED3.2 (A), R30.2
unnamed: LED3.1 (K), U5.1 (STAT)
unnamed: R16.1, R33.1
unnamed: R36.1, U5.18 (BATP)
unnamed: C37.2, C38.2, C39.2, C40.2, U5.29 (PMID)
unnamed: C41.2, U5.24 (SDRV)
unnamed: R34.2, R38.1, R50.2, U5.16 (TS)
unnamed: R31.1, U5.13 (~CE)
unnamed: C46.2, C47.2, C48.2, R72.2, R73.2, U6.5 (EN), U6.6 (VIN)
unnamed: R42.2, U6.7 (MODE/S-CONF)
unnamed: TP1.1 (1_1), U6.1 (PG)
unnamed: C49.2, U6.8 (SS/TR)
unnamed: L2.2, U6.2 (SW)
PGND: Battery1.2, C23.1, C26.1, C27.1, C30.1, C31.1, C33.1, C34.1, C35.1, C36.1, C37.1, C38.1, C39.1, C40.1, C41.1, C42.1, C43.1, C44.1, C45.1, C46.1, C47.1, C48.1, C49.1, C89.1, C90.1, C91.1, C94.1, D3.2, DC1.2, DC1.3, DC1.4, FB1.2, R31.2, R33.2, R37.1, R38.2, R40.1, R42.1, R50.1, Solarpower1.2, U5.27 (GND), U6.4 (GND); also elsewhere on the board

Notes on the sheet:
Can it be replaced with YSMC0420V-1R0M
R39(200K), R40(27K), R41(0R) = 5V
127K for 1.5A charging 255K for 0.5A charging

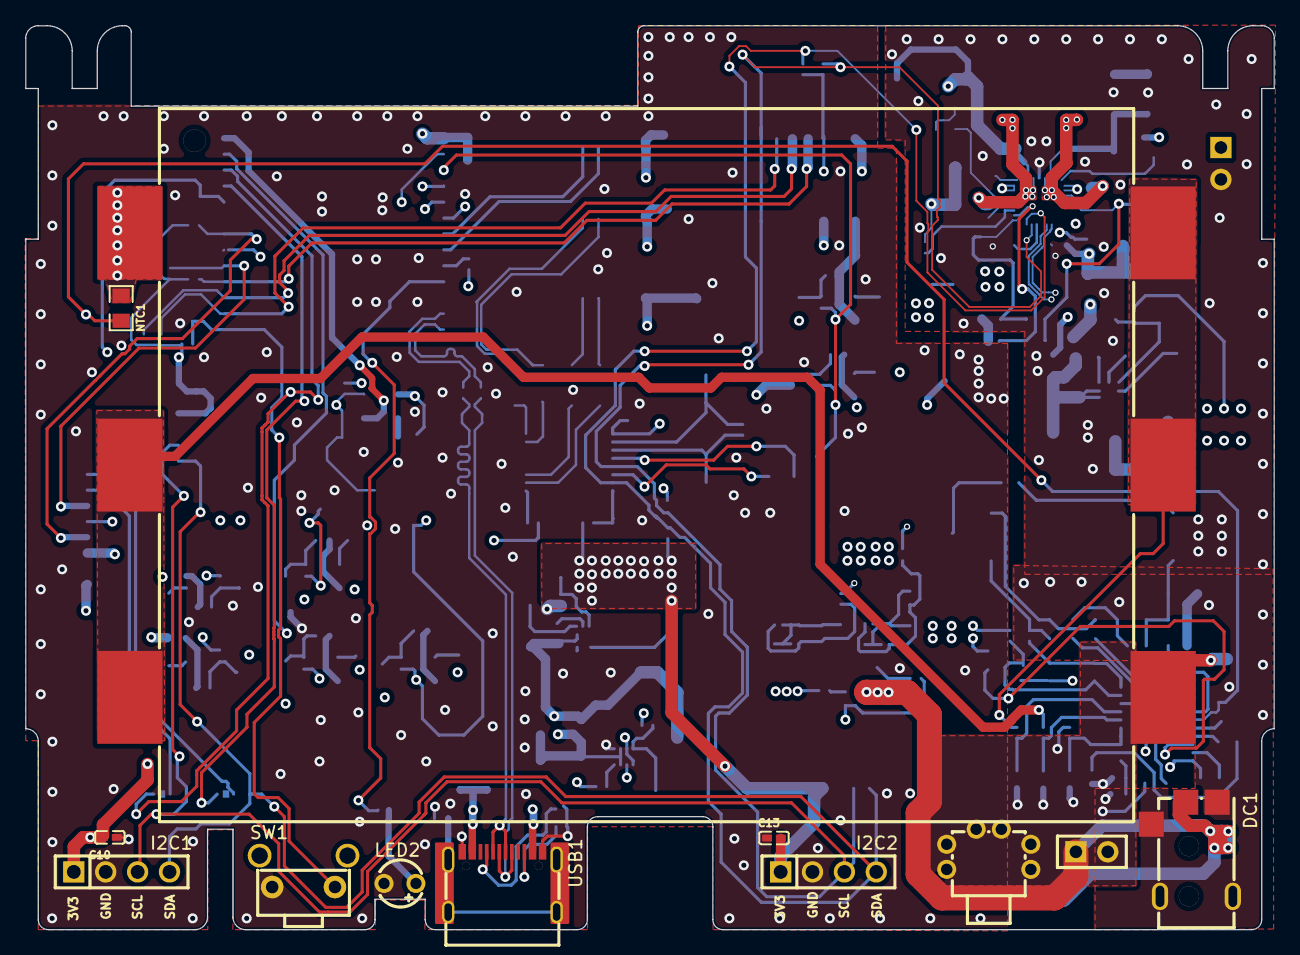
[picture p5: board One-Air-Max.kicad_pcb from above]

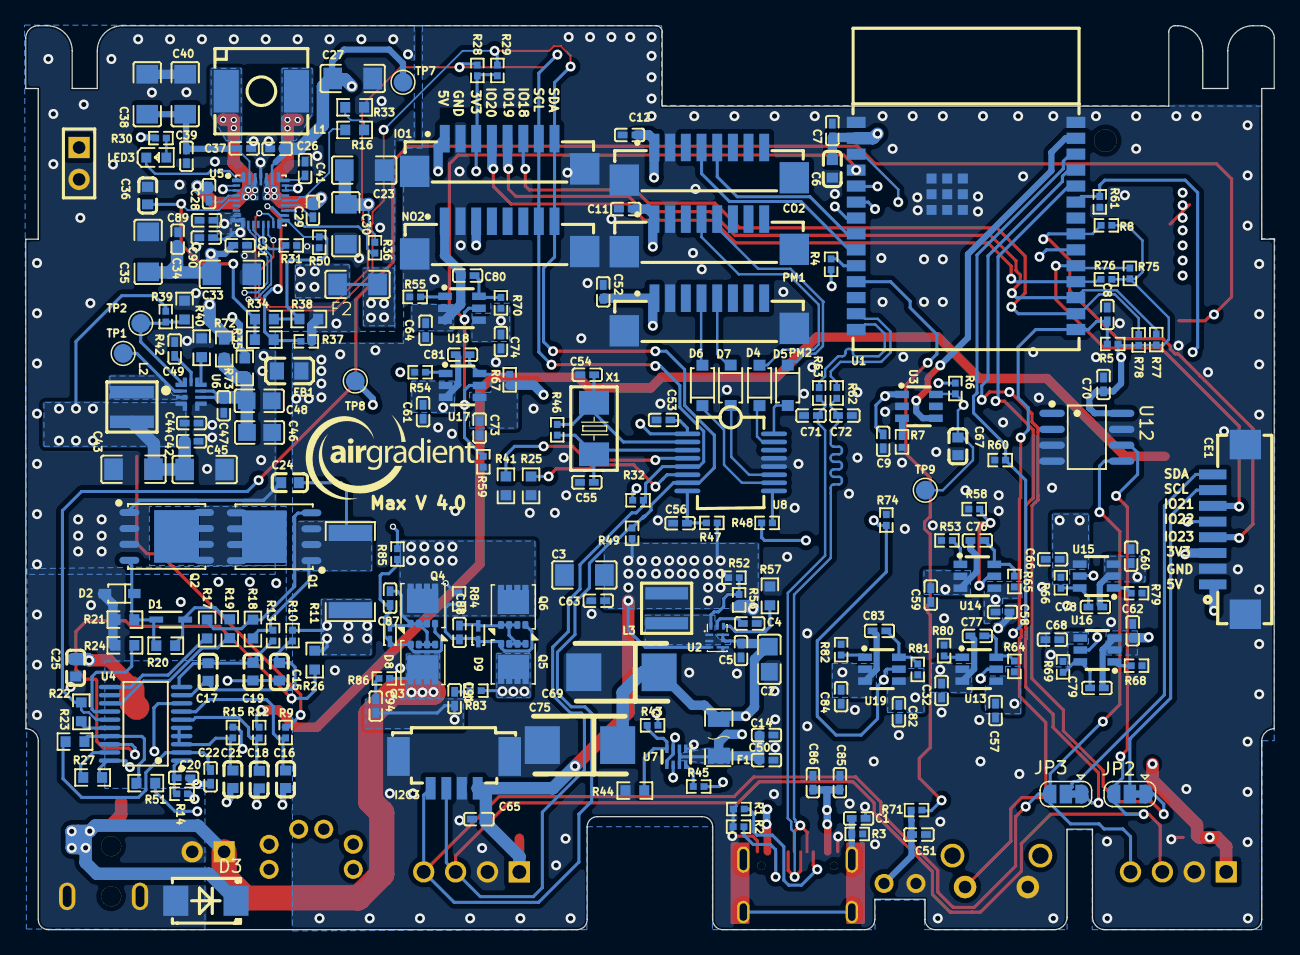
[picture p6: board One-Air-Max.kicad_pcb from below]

Board: 4 copper layers, 99.5 x 72.0 mm, 242 parts (230 on the bottom side), 138 nets.

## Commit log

2026-09-01 Import OpenAir Max hardware v4.0
    Imported from the official Bitbucket repository airgradient/openair-max-pcb
    at tag v4.0 (commit 66be3d9), with one deliberate design change on top of
    the official tag:
    - Mark U12 (AT24CM02 EEPROM) and C70 as DNP in the schematic. The archived
    v4.0 production set predates this and still lists both parts. (KiCad also
    dropped a stale duplicate R20 symbol-instance record on resave.)
    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
    [Battery-Holder.kicad_sch, One-Air-Max.kicad_pcb, One-Air-Max.kicad_sch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]
2026-09-30 Fix 3D models for STEP export
    Add STEP versions of the easyeda2kicad models (from the global
    easyeda2kicad library) so --subst-models can replace the VRML models
    when exporting STEP.
    Q3-Q6: point the model at the NexFET .step, since KiCad 10 no longer
    ships the .wrl. D2: point the model at SOD-323_L1.8-W1.3-LS2.5-RD to
    match its footprint; the old SOD-323_L1.7 model file never existed.
    [One-Air-Max.kicad_pcb]
